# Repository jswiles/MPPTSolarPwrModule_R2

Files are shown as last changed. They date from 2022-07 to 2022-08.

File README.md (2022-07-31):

# MPPTSolarPwrModule_R2

MPPT Solar Power Module Revision 2

- 3.7V LiPo cell
- INA3221 Current/Voltage Monitor
    - Solar Panel Input
    - Battery Cell Output
    - Load Output 
- 6V/12V Solar Panel Selection
- Load Sharing of Solar Panel and Battery
- Regulated 6V output

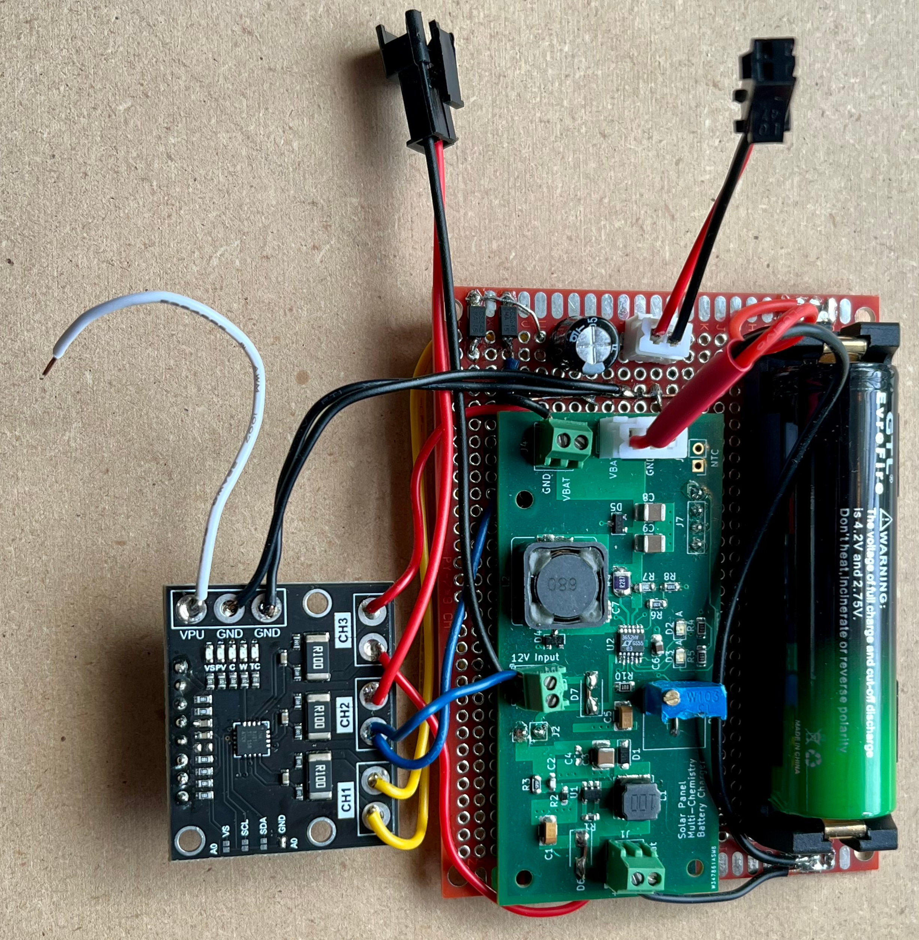
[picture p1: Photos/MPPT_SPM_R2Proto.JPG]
MPPTSPM_Proto MPPT Solar Power Module Revision 2 Prototype


Revision 2 prototype and test using Revision 1 board.

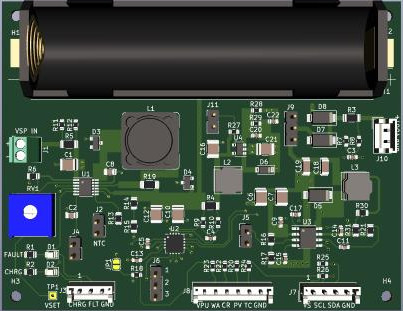
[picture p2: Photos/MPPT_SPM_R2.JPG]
MPPTSPM_R2 MPPT Solar Power Module Revision 2


Revision 2 3D Model

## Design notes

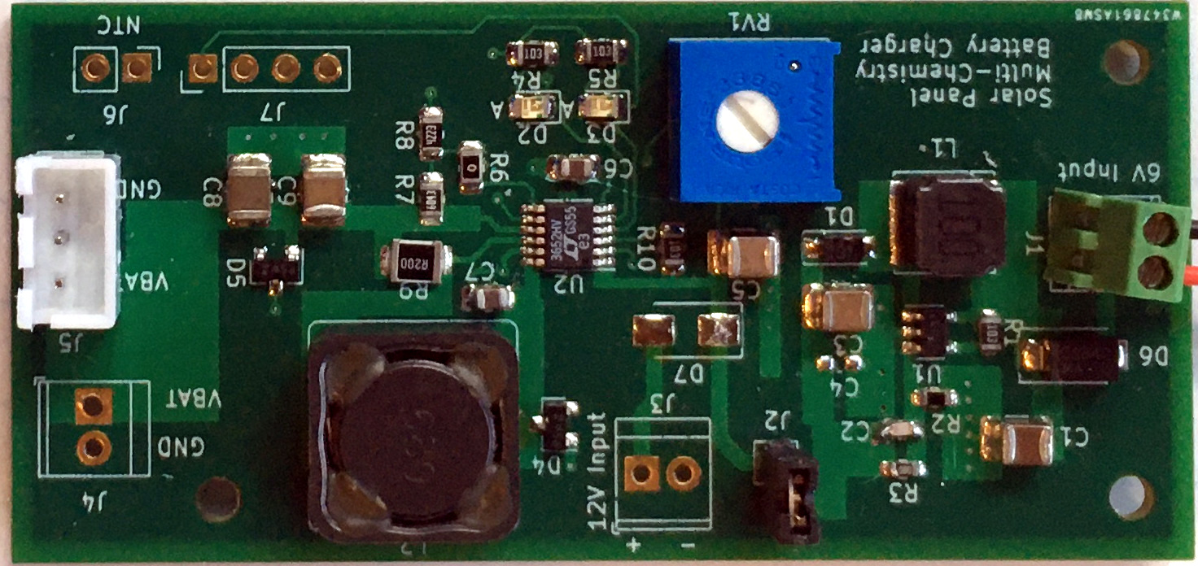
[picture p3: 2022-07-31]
Photos/MPPT_SPM_R1.JPG

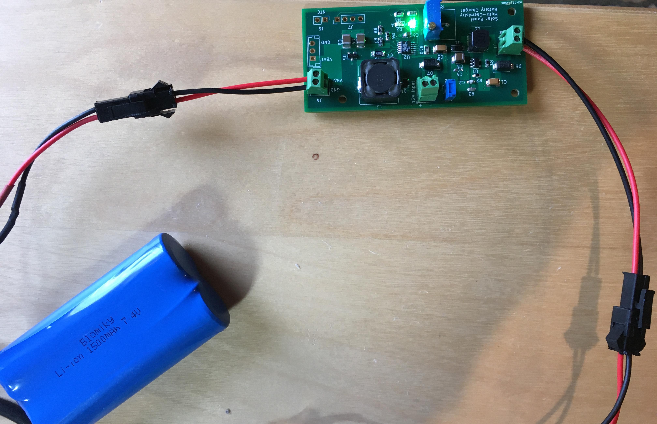
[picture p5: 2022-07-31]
Photos/MPPT_SPMR1_DEMO.JPG

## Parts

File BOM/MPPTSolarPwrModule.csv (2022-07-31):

Reference | Quantity | Value | Footprint | Datasheet | DigiKey | Mouser | Mouser
BT1 | 1 | Battery_Cell | Battery:BatteryHolder_Keystone_1042_1x18650 | ~ |  | 534-1042
C1 C10 C16 | 3 | 10uF | Capacitor_SMD:C_1210_3225Metric | ~ | 587-1965-1-ND |  | 81-GCM32EL8EH106KA7L
C11 | 1 | 1000pF | Capacitor_SMD:C_0603_1608Metric | ~
C12 | 1 | 100uF | Capacitor_SMD:C_1210_3225Metric | ~ | 587-1965-1-ND | 771-PMEG4005ET-T/R
C14 | 1 | 47pF | Capacitor_SMD:C_0603_1608Metric | ~
C15 | 1 | 0.15uF | Capacitor_SMD:C_0603_1608Metric | ~
C18 C19 | 2 | 47uF | Capacitor_SMD:C_1206_3216Metric | ~
C20 | 1 | 220pF | Capacitor_SMD:C_0603_1608Metric | ~ |  | 346-CM21X5R475K25AT
C6 C7 C21 | 3 | 4.7uF | Capacitor_SMD:C_1210_3225Metric | ~ | 490-1864-1-ND
C22 | 1 | 0.022uF | Capacitor_SMD:C_0603_1608Metric | ~ | 490-3884-1-ND
C3 C4 C5 C13 C17 | 5 | 0.1uF | Capacitor_SMD:C_0603_1608Metric | ~
C2 C8 | 2 | 1uF | Capacitor_SMD:C_0805_2012Metric | ~ | 445-6961-1-ND |  | 346-CM21X5R475K25AT
C9 | 1 | 0.01uF | Capacitor_SMD:C_0603_1608Metric | ~
D1 | 1 | LED-RED | LED_SMD:LED_0805_2012Metric | ~ | 754-1128-1-ND
D2 | 1 | LED-GRN | LED_SMD:LED_0805_2012Metric | ~ | 754-1795-1-ND
D3 D4 | 2 | PMEG4005ET,215 | Diode_SMD:D_SOT-23_ANK | ~ | 1727-3878-1-ND | 771-PMEG4005ET-T/R
D5 | 1 | B240A | Diode_SMD:D_SMA | ~
D6 | 1 | 40V | Diode_SMD:D_SOD-123 | ~ | RB168MM-40CT-ND | 755-RB168MM-40TR
D7 D8 | 2 | CMSH3-40mA | Diode_SMD:D_SMA | ~ | 1514-CMSH3-40MATR13PBFREECT-ND | 610-CMSH3-40MA
H1 H2 H3 H4 | 4 | MountingHole | MountingHole:MountingHole_2.5mm | ~
J1 | 1 | Screw_Terminal_01x02 | TerminalBlock_Phoenix:TerminalBlock_Phoenix_MPT-0,5-2-2.54_1x02_P2.54mm_Horizontal | ~ |  | 651-1725656
J10 | 1 | Conn_01x02 | Connector_JST:JST_EH_B2B-EH-A_1x02_P2.50mm_Vertical | ~
J2 J4 J5 J11 | 4 | Conn_01x02 | Connector_PinHeader_2.54mm:PinHeader_1x02_P2.54mm_Vertical | ~
J3 | 1 | Conn_01x03 | Connector_JST:JST_EH_B3B-EH-A_1x03_P2.50mm_Vertical | ~
J7 | 1 | Conn_01x04 | Connector_JST:JST_EH_B4B-EH-A_1x04_P2.50mm_Vertical | ~
J8 | 1 | Conn_01x06 | Connector_JST:JST_EH_B6B-EH-A_1x06_P2.50mm_Vertical | ~
J6 J9 | 2 | Conn_01x03 | Connector_PinHeader_2.54mm:PinHeader_1x03_P2.54mm_Vertical | ~
JP1 | 1 | SolderJumper_2_Open | Jumper:SolderJumper-2_P1.3mm_Open_RoundedPad1.0x1.5mm | ~
L1 | 1 | 68uH | Inductor_SMD:L_Bourns_SRR1260 | ~ | SRR1260-680MCT-ND | 652-SRR1260-680M
L2 L3 | 2 | 10uH | Inductor_SMD:L_Bourns_SRN6045TA | ~ | SRN6045-100MCT-ND | 652-SRN6045TA-100M
R1 R2 R6 | 3 | 10K | Resistor_SMD:R_0805_2012Metric | ~ | RMCF0805JT10K0CT-ND
R13 | 1 | 182K | Resistor_SMD:R_0805_2012Metric | ~
R14 | 1 | 84.5K | Resistor_SMD:R_0805_2012Metric | ~
R15 | 1 | 330K | Resistor_SMD:R_0805_2012Metric | ~
R16 | 1 | 332K | Resistor_SMD:R_0805_2012Metric | ~ | RMCF0805JT10K0CT-ND
R17 | 1 | 68.1K | Resistor_SMD:R_0805_2012Metric | ~ | RMCF0805JT10K0CT-ND
R19 | 1 | 0.5 | Resistor_SMD:R_1206_3216Metric_Pad1.30x1.75mm_HandSolder | ~ | 13-RL1206FR-7W0R5LCT-ND | 652-CRL1206FWR130ELF
R21 | 1 | 29.4K | Resistor_SMD:R_0805_2012Metric | ~ | RMCF0805JT10K0CT-ND
R18 R20 R22 R23 R24 R25 R26 R27 | 8 | 10K | Resistor_SMD:R_0603_1608Metric | ~
R28 | 1 | 13.3K | Resistor_SMD:R_0603_1608Metric | ~ | CRCW060313K3FKEA | 603-RT0603FRE0713K3L
R29 | 1 | 52.3K | Resistor_SMD:R_0603_1608Metric | ~
R3 R4 R5 | 3 | 0.100 | Resistor_SMD:R_1206_3216Metric | ~
R30 | 1 | 10.2K | Resistor_SMD:R_0805_2012Metric | ~ | RMCF0805JT10K0CT-ND
R31 | 1 | 1.54K | Resistor_SMD:R_0805_2012Metric | ~ | RMCF0805JT10K0CT-ND
R7 R8 R9 R10 R11 R12 | 6 | 10 | Resistor_SMD:R_0603_1608Metric | ~
RV1 | 1 | 10K | 3386F-1-103LF:Potentiometer_Bourns_3386F_Vertical | ~ | 3386F-103LF-ND |  | 652-3386F-1-103LF
TP1 | 1 | TestPoint_Flag | TestPoint:TestPoint_THTPad_1.5x1.5mm_Drill0.7mm | ~
U1 | 1 | LT3652EDD | Package_SO:MSOP-12-1EP_3x4mm_P0.65mm_EP1.65x2.85mm | https://www.analog.com/media/en/technical-documentation/data-sheets/3652fe.pdf | LT3652HVEDD#PBF-ND | 584-LT3652HVIMSE#PBF
U2 | 1 | INA3221 | INA3221AIRGVT:Texas_RGV_S-PVQFN-N16_EP2.1x2.1mm | http://www.ti.com/lit/ds/symlink/ina3221.pdf
U3 | 1 | TPS54233 | Package_SO:SOIC-8_3.9x4.9mm_P1.27mm | http://www.ti.com/lit/ds/symlink/tps54233.pdf
U4 | 1 | LMR62014XMF | Package_TO_SOT_SMD:SOT-23-5 | http://www.ti.com/lit/ds/symlink/lmr62014.pdf | LMR62014XMF/NOPBCT-ND | 926-LMR62014XMF/NOPB

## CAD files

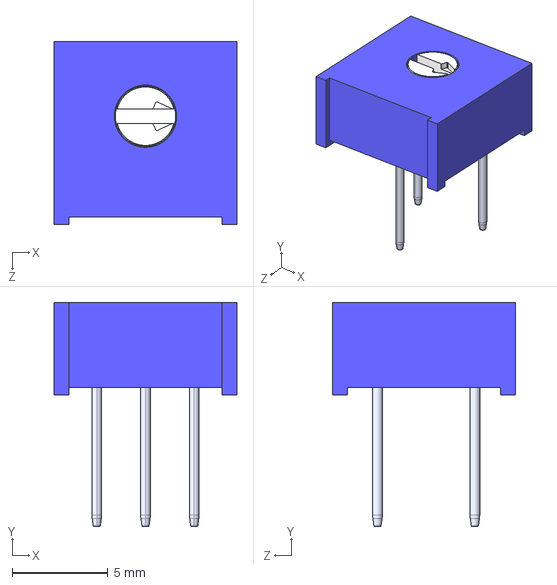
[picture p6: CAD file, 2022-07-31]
KiCAD_Models/3386F-1-103LF/3386F-1-103LF.STEP
9.53 x 11.7 x 9.53 mm

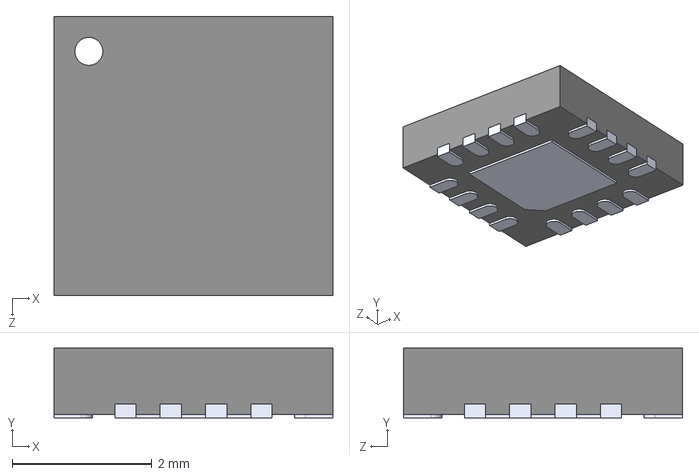
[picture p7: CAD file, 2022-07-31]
KiCAD_Models/INA3221AIRGVT/INA3221AIRGVT.STEP
4.00 x 1.00 x 4.00 mm

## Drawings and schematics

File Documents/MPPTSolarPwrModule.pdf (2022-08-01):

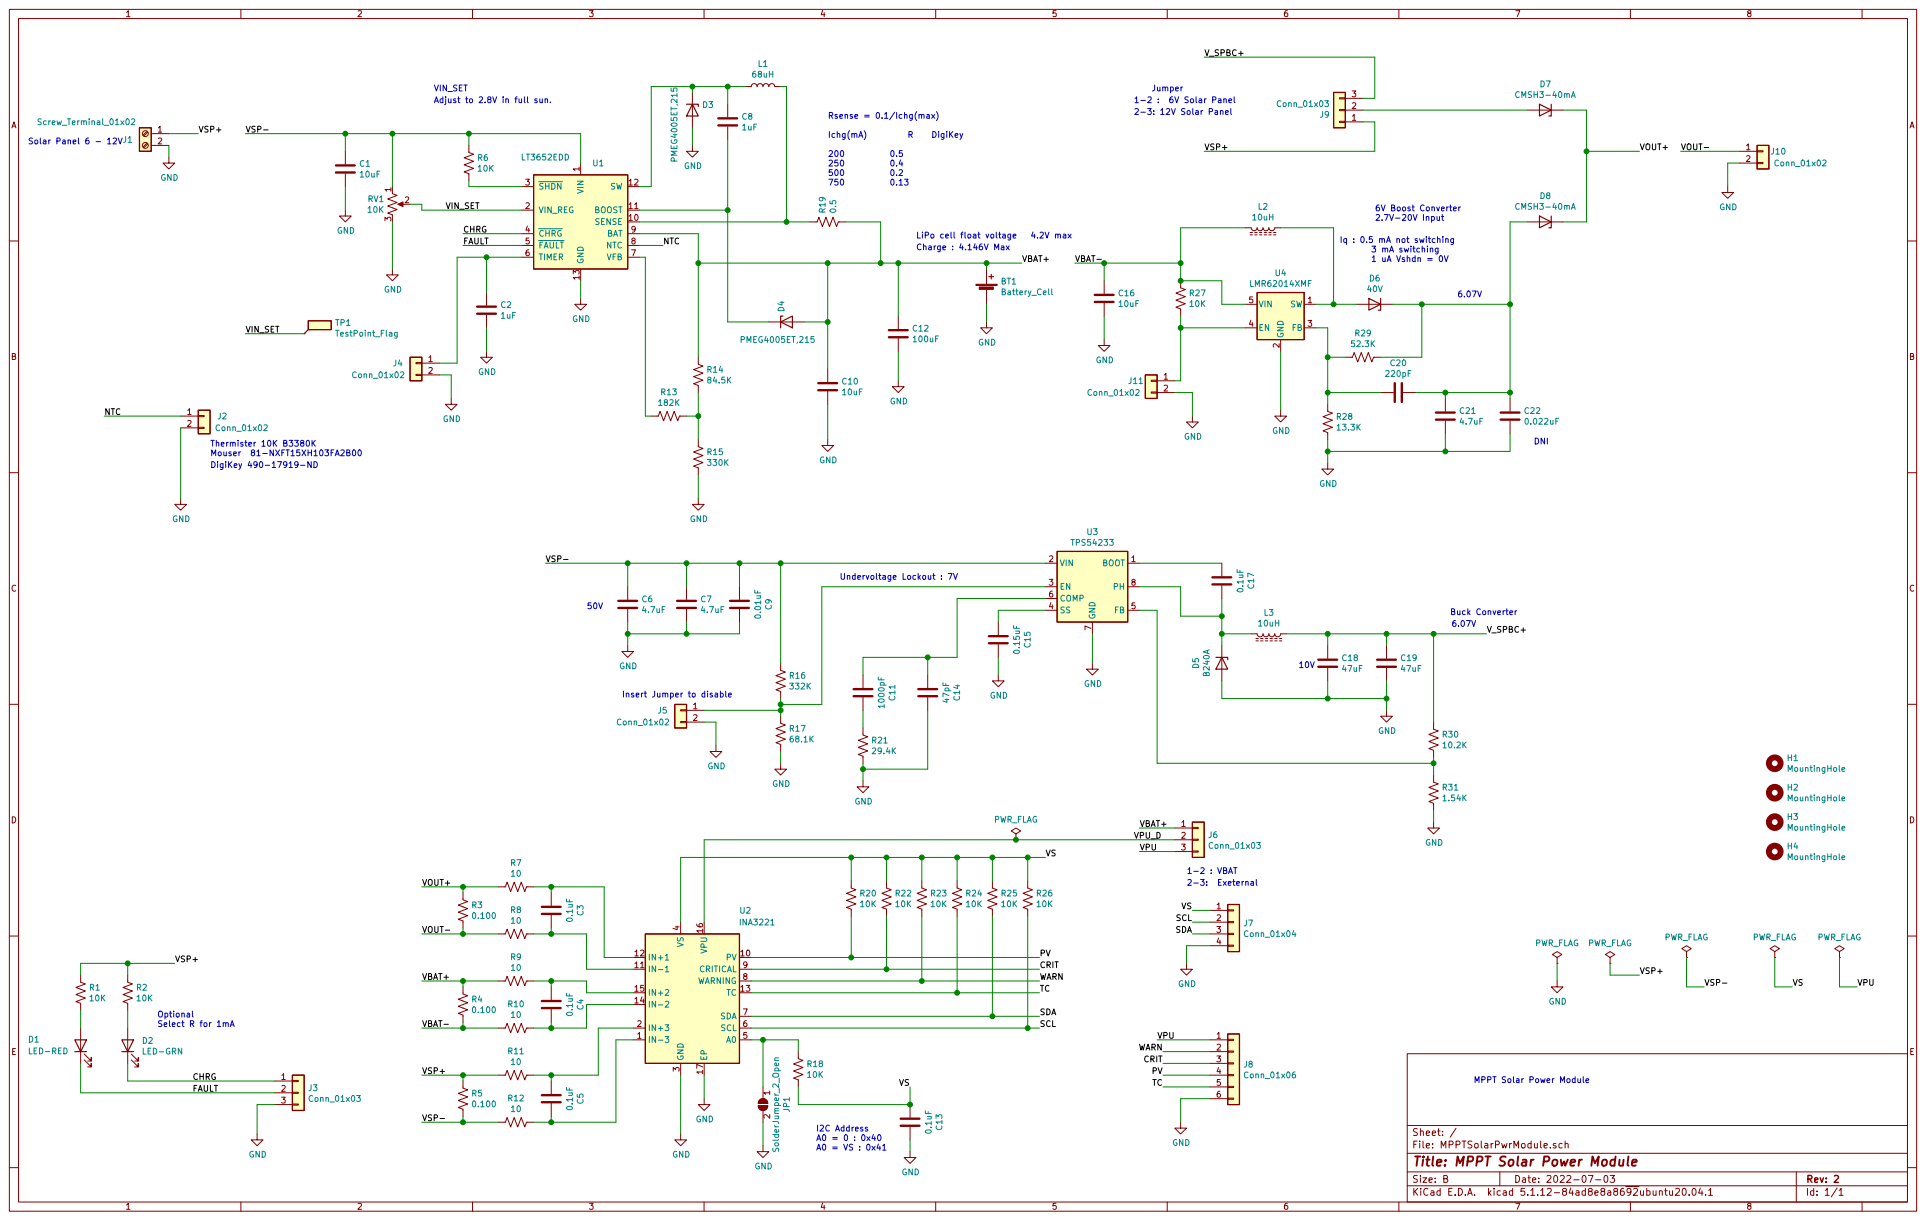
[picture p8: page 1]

1 SENSE 10 BOOST 11 SW 12 GND 13 VIN_REG 2 SHDN 3 CHRG 4 FAULT 5 TIMER 6 VFB 7 NTC 8 BAT 9 U1 LT3652EDD

Insert Jumper to disable Thermister 10K B3380K Mouser 81-NXFT15XH103FA2B00 DigiKey 490-17919-ND

VSP- VSP+ VOUT- VOUT+ VBAT- VBAT+ VSP+

4 A0 5 SCL 6 SDA 7 WARNING 8 CRITICAL 9U2

MPPT Solar Power Module

File: MPPTSolarPwrModule.sch Sheet: /
Id: 1/1 Title: MPPT Solar Power Module

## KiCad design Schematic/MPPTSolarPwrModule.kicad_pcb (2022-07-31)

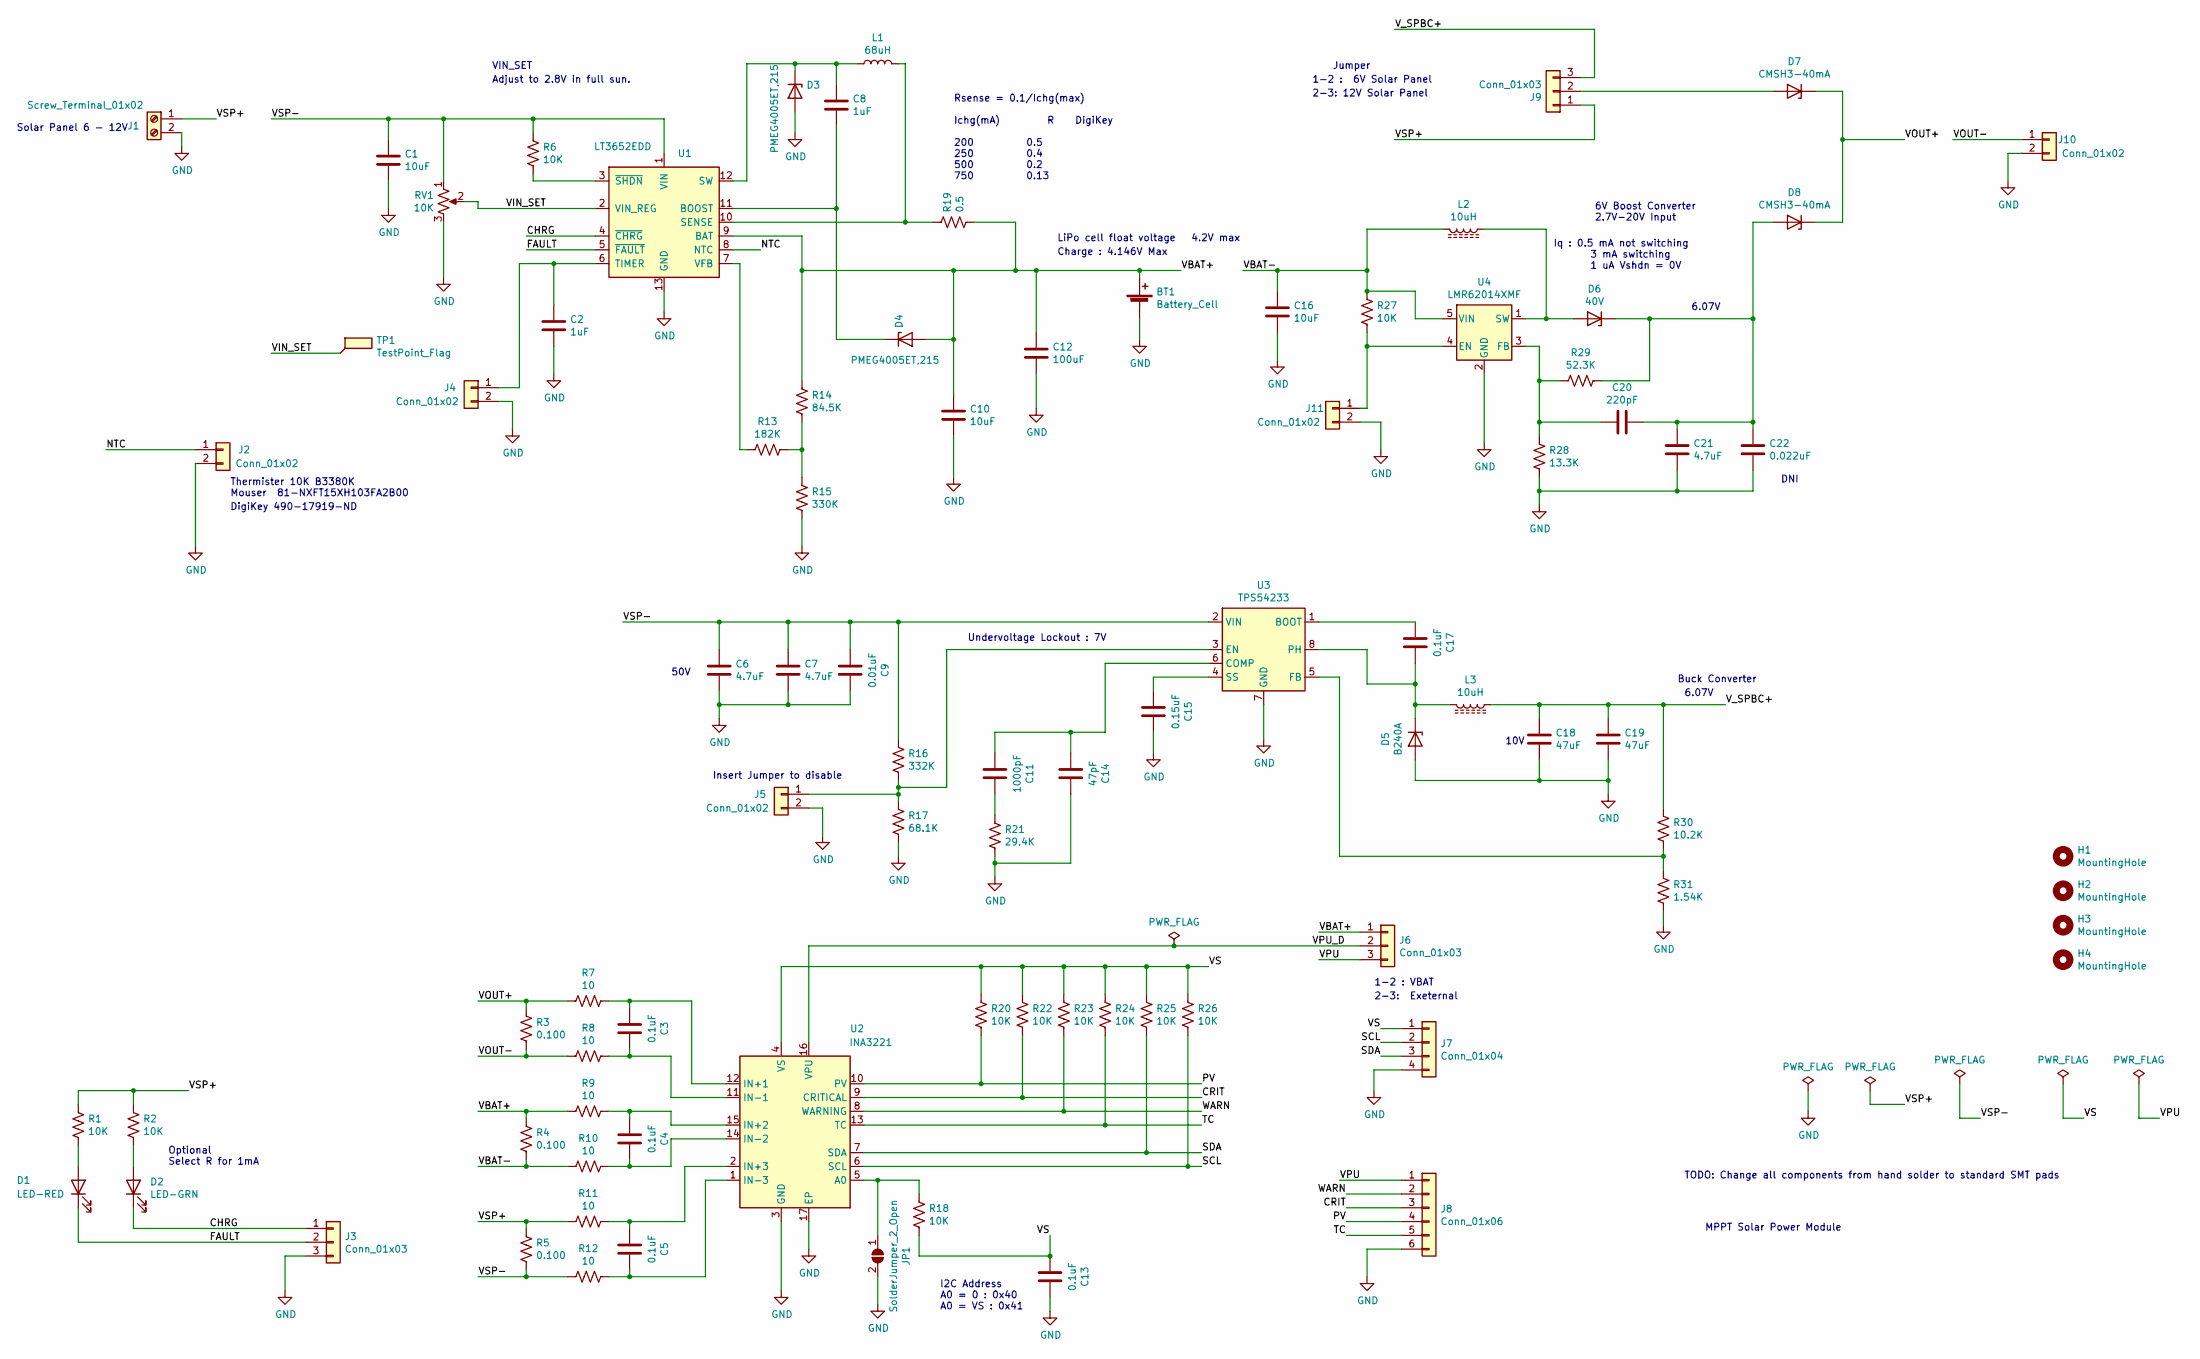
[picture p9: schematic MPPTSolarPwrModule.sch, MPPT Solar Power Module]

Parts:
BT1: Battery_Cell; BatteryHolder_Keystone_1042_1x18650; Mouser 534-1042
C1, C10, C16: 10uF; C_1210_3225Metric; DigiKey 587-1965-1-ND
C2, C8: 1uF; C_0805_2012Metric; DigiKey 445-6961-1-ND
C3, C4, C5, C13, C17: 0.1uF; C_0603_1608Metric
C6, C7: 4.7uF; C_1210_3225Metric; Mouser 603-CC1210KFX7R9B475
C9: 0.01uF; C_0603_1608Metric
C11: 1000pF; C_0603_1608Metric
C12: 100uF; C_1210_3225Metric; DigiKey 587-1965-1-ND
C14: 47pF; C_0603_1608Metric
C15: 0.15uF; C_0603_1608Metric
C18, C19: 47uF; C_1206_3216Metric
C20: 220pF; C_0603_1608Metric; Mouser 346-CM21X5R475K25AT
C21: 4.7uF; C_1210_3225Metric; DigiKey 490-1864-1-ND
C22: 0.022uF; C_0603_1608Metric; DigiKey 490-3884-1-ND
D1: LED-RED; LED_0805_2012Metric; DigiKey 754-1128-1-ND
D2: LED-GRN; LED_0805_2012Metric; DigiKey 754-1795-1-ND
D3, D4: PMEG4005ET,215; D_SOT-23_ANK; DigiKey 1727-3878-1-ND
D5: B240A; D_SMA
D6: 40V; D_SOD-123; DigiKey RB168MM-40CT-ND
D7, D8: CMSH3-40mA; D_SMA; DigiKey 1514-CMSH3-40MATR13PBFREECT-ND
H1, H2, H3, H4: MountingHole; MountingHole_2.5mm
J1: Screw_Terminal_01x02; TerminalBlock_Phoenix_MPT-0,5-2-2.54_1x02_P2.54mm_Horizontal; Mouser 651-1725656
J2, J4, J5, J11: Conn_01x02; PinHeader_1x02_P2.54mm_Vertical
J3: Conn_01x03; JST_EH_B3B-EH-A_1x03_P2.50mm_Vertical
J6, J9: Conn_01x03; PinHeader_1x03_P2.54mm_Vertical
J7: Conn_01x04; JST_EH_B4B-EH-A_1x04_P2.50mm_Vertical
J8: Conn_01x06; JST_EH_B6B-EH-A_1x06_P2.50mm_Vertical
J10: Conn_01x02; JST_EH_B2B-EH-A_1x02_P2.50mm_Vertical
JP1: SolderJumper_2_Open; SolderJumper-2_P1.3mm_Open_RoundedPad1.0x1.5mm
L1: 68uH; L_Bourns_SRR1260; DigiKey SRR1260-680MCT-ND
L2, L3: 10uH; L_Bourns_SRN6045TA; DigiKey SRN6045-100MCT-ND
R1, R2, R6: 10K; R_0805_2012Metric; DigiKey RMCF0805JT10K0CT-ND
R3, R4, R5: 0.100; R_1206_3216Metric
R7, R8, R9, R10, R11, R12: 10; R_0603_1608Metric
R13: 182K; R_0805_2012Metric
R14: 84.5K; R_0805_2012Metric
R15: 330K; R_0805_2012Metric
R16: 332K; R_0805_2012Metric; DigiKey RMCF0805JT10K0CT-ND
R17: 68.1K; R_0805_2012Metric; DigiKey RMCF0805JT10K0CT-ND
R18, R20, R22, R23, R24, R25, R26: 10K; R_0603_1608Metric; DigiKey RMCF0805JT10K0CT-ND
R19: 0.5; R_1206_3216Metric_Pad1.30x1.75mm_HandSolder; DigiKey 13-RL1206FR-7W0R5LCT-ND
R21: 29.4K; R_0805_2012Metric; DigiKey RMCF0805JT10K0CT-ND
R27: 10K; R_0603_1608Metric
R28: 13.3K; R_0603_1608Metric; DigiKey CRCW060313K3FKEA
R29: 52.3K; R_0603_1608Metric
R30: 10.2K; R_0805_2012Metric; DigiKey RMCF0805JT10K0CT-ND
R31: 1.54K; R_0805_2012Metric; DigiKey RMCF0805JT10K0CT-ND
RV1: 10K; Potentiometer_Bourns_3386F_Vertical; DigiKey 3386F-103LF-ND
TP1: TestPoint_Flag; TestPoint_THTPad_1.5x1.5mm_Drill0.7mm
U1: LT3652EDD; MSOP-12-1EP_3x4mm_P0.65mm_EP1.65x2.85mm; DigiKey LT3652HVEDD#PBF-ND
U2: INA3221; Texas_RGV_S-PVQFN-N16_EP2.1x2.1mm
U3: TPS54233; SOIC-8_3.9x4.9mm_P1.27mm
U4: LMR62014XMF; SOT-23-5; DigiKey LMR62014XMF/NOPBCT-ND

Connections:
/CHRG: D2.1 (K), J3.1, U1.4 (~CHRG)
/CRIT: J8.3, R22.2, U2.9 (CRITICAL)
/FAULT: D1.1 (K), J3.2, U1.5 (~FAULT)
/NTC: J2.1, U1.8 (NTC)
/PV: J8.4, R20.2, U2.10 (PV)
/SCL: J7.2, R26.2, U2.6 (SCL)
/SDA: J7.3, R25.2, U2.7 (SDA)
/TC: J8.5, R24.2, U2.13 (TC)
/VBAT+: BT1.1 (+), C10.1, C12.1, D4.2 (A), J6.1, R4.1, R9.2, R14.1, R19.2, U1.9 (BAT)
/VBAT-: C16.1, L2.2, R4.2, R10.2, R27.1, U4.5 (VIN)
/VIN_SET: RV1.2, TP1.1, U1.2 (VIN_REG)
/VOUT+: D7.1 (K), D8.1 (K), R3.1, R7.2
/VOUT-: J10.1, R3.2, R8.2
/VPU: J6.3, J8.1
/VPU_D: J6.2, U2.16 (VPU)
/VS: C13.2, J7.1, R18.2, R20.1, R22.1, R23.1, R24.1, R25.1, R26.1, U2.4 (VS)
/VSP+: J1.1, J9.1, R1.1, R2.1, R5.1, R11.2
/VSP-: C1.1, C6.1, C7.1, C9.2, R5.2, R6.1, R12.2, R16.1, RV1.1, U1.1 (VIN), U3.2 (VIN)
/V_SPBC+: C18.1, C19.1, J9.3, L3.1, R30.1
/WARN: J8.2, R23.2, U2.8 (WARNING)
GND: BT1.2 (-), C1.2, C2.2, C6.2, C7.2, C9.1, C10.2, C12.2, C13.1, C14.1, C15.1, C16.2, C18.2, C19.2, C21.2, C22.2, D3.2 (A), D5.2 (A), J1.2, J2.2, J3.3, J4.2, J5.2, J7.4, J8.6, J10.2, J11.2, JP1.2 (B), R15.2, R17.2, R21.2, R28.2, R31.2, RV1.3, U1.13 (GND), U2.3 (GND), U2.17 (EP), U3.7 (GND), U4.2 (GND)
unnamed: C2.1, J4.1, U1.6 (TIMER)
unnamed: C3.1, R8.1, U2.11 (IN-1)
unnamed: C3.2, R7.1, U2.12 (IN+1)
unnamed: C4.1, R10.1, U2.14 (IN-2)
unnamed: C4.2, R9.1, U2.15 (IN+2)
unnamed: C5.1, R12.1, U2.1 (IN-3)
unnamed: C5.2, R11.1, U2.2 (IN+3)
unnamed: C8.1, D3.1 (K), L1.1, U1.12 (SW)
unnamed: C8.2, D4.1 (K), U1.11 (BOOST)
unnamed: C11.1, R21.1
unnamed: C11.2, C14.2, U3.6 (COMP)
unnamed: C15.2, U3.4 (SS)
unnamed: C17.1, D5.1 (K), L3.2, U3.8 (PH)
unnamed: C17.2, U3.1 (BOOT)
unnamed: C20.1, C21.1, C22.1, D6.1 (K), D8.2 (A), R29.1
unnamed: C20.2, R28.1, R29.2, U4.3 (FB)
unnamed: D1.2 (A), R1.2
unnamed: D2.2 (A), R2.2
unnamed: D6.2 (A), L2.1, U4.1 (SW)
unnamed: D7.2 (A), J9.2
unnamed: J5.1, R16.2, R17.1, U3.3 (EN)
unnamed: J11.1, R27.2, U4.4 (EN)
unnamed: JP1.1 (A), R18.1, U2.5 (A0)
unnamed: L1.2, R19.1, U1.10 (SENSE)
unnamed: R6.2, U1.3 (~SHDN)
unnamed: R13.1, R14.2, R15.1
unnamed: R13.2, U1.7 (VFB)
unnamed: R30.2, R31.1, U3.5 (FB)

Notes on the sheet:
6V Boost Converter 2.7V-20V Input
Thermister 10K B3380K Mouser 81-NXFT15XH103FA2B00
DigiKey 490-17919-ND
Solar Panel 6 - 12V
Optional Select R for 1mA
Rsense = 0.1/Ichg(max) Ichg(mA) R DigiKey 200 0.5 250 0.4 500 0.2 750 0.13
LiPo cell float voltage 4.2V max
DNI
Buck Converter
VIN_SET
Adjust to 2.8V in full sun.
Charge : 4.146V Max
6.07V
1-2 : 6V Solar Panel
2-3: 12V Solar Panel
Jumper
10V
50V
Iq : 0.5 mA not switching 3 mA switching 1 uA Vshdn = 0V
MPPT Solar Power Module
I2C Address A0 = 0 : 0x40 A0 = VS : 0x41
Insert Jumper to disable
Undervoltage Lockout : 7V
1-2 : VBAT
2-3: Exeternal
TODO: Change all components from hand solder to standard SMT pads

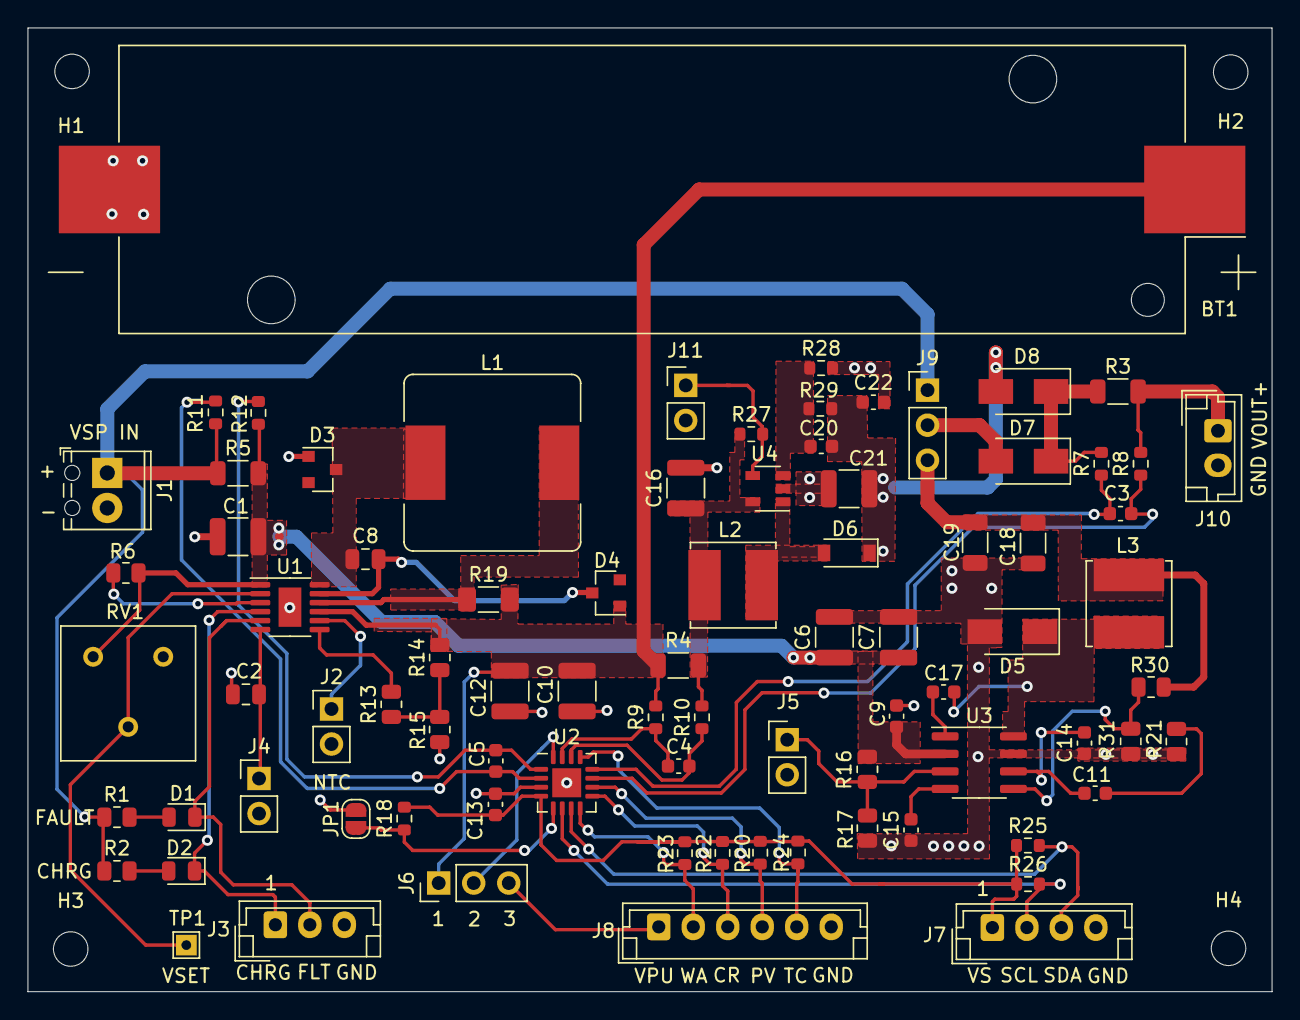
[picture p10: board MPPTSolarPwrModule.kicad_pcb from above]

Board: 4 copper layers, 90.2 x 69.8 mm, 87 parts (0 on the bottom side), 49 nets.

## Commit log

2022-07-31 Added BOM, PCB and Schematics
    [3386F-1-103LF.STEP, INA3221AIRGVT.STEP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]
2022-08-01 Added KiCad 3D models, Documents, and updated schematic
    [MPPTSolarPwrModule.sch]
